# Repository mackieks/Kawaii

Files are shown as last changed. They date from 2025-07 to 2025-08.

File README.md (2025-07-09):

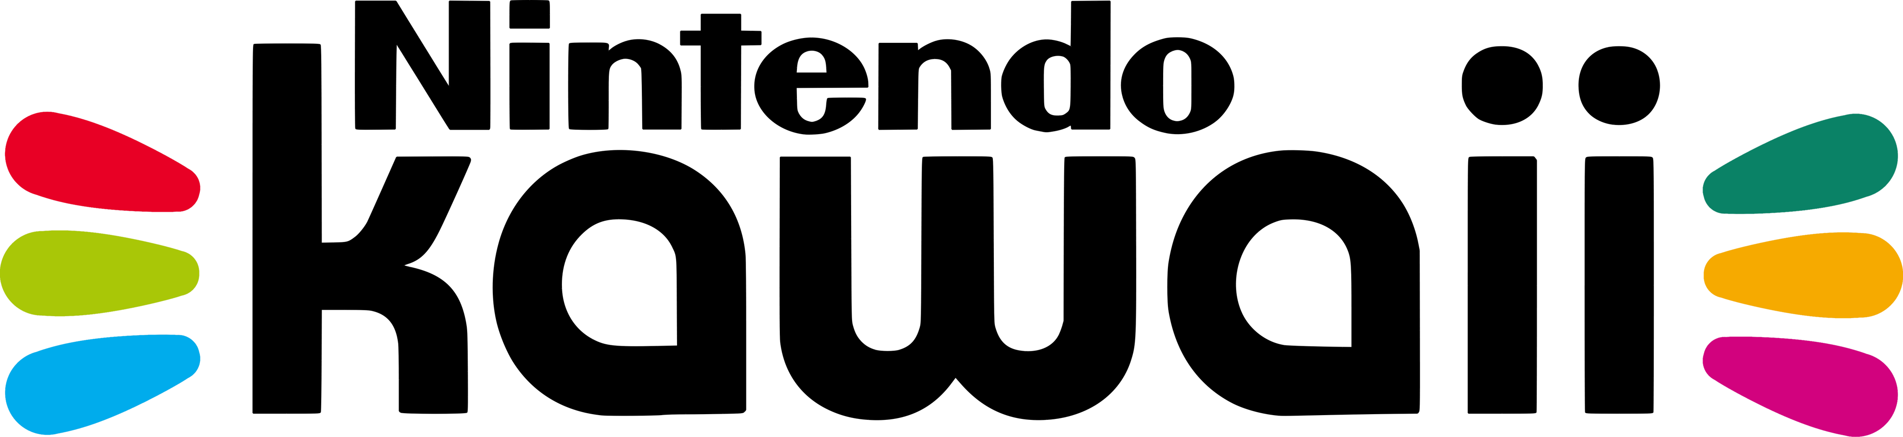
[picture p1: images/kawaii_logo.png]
<picture> <source media="(prefers-color-scheme: dark)" srcset="images/kawaii_logo_white.png">  </picture> 

Kawaii is a functional metal Nintendo Wii keychain created by YveltalGriffin, Wesk and Ding.

It's a technical tour de force that prioritizes aesthetics over practicality, and **fully** utilizes the OMEGA trim.

Kawaii may be the zenith of Wii portablizing as an artform.
  


## Features:
- [x] 60 x 60 x 15.8mm CNC aluminum chassis
- [x] Anodized, with laser-etched artwork
- [x] Fake compliance markings
- [x] Keychain / tassel loop
- [x] OMEGA-trimmed undervolted Hollywood-2 Wii Mini motherboard
- [x] [AVEflex](https://github.com/mackieks/AVEflex) and [nandFlex](https://github.com/mackieks/nandFlex)
- [x] Powered by [Thundervolt](https://github.com/mackieks/thundervolt)
- [x] Internal microSD card for homebrew and games
- [x] Six internal addressable RGB LEDs
- [x] Magnetic pogo pin docking connector
- [x] Composite video, 480p YPbPr, and stereo audio output
- [x] 4-player GameCube controller connectivity via magnetic dock

## Gallery



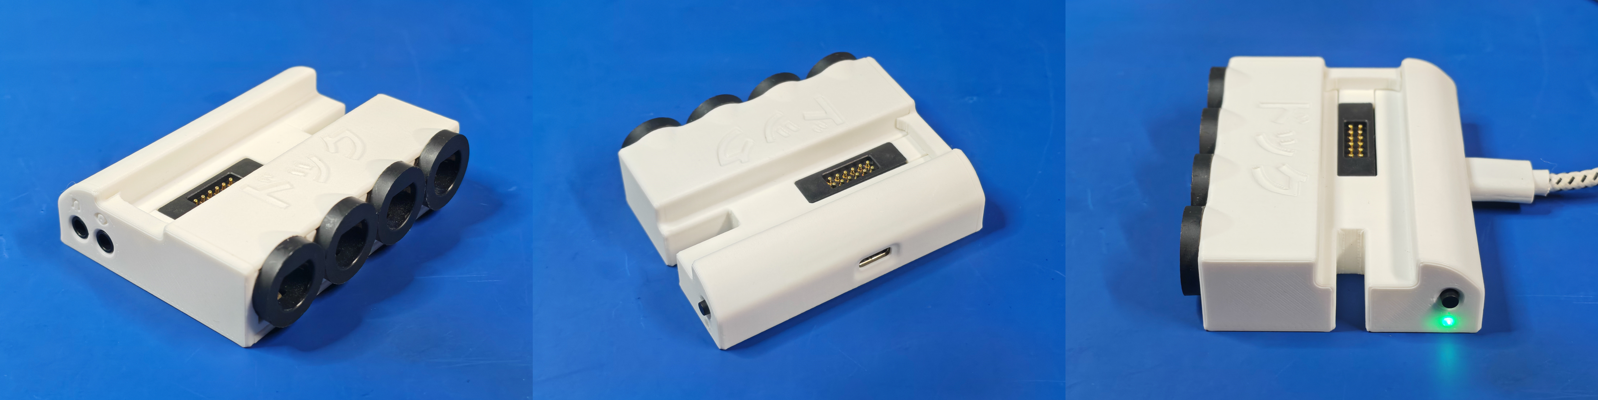
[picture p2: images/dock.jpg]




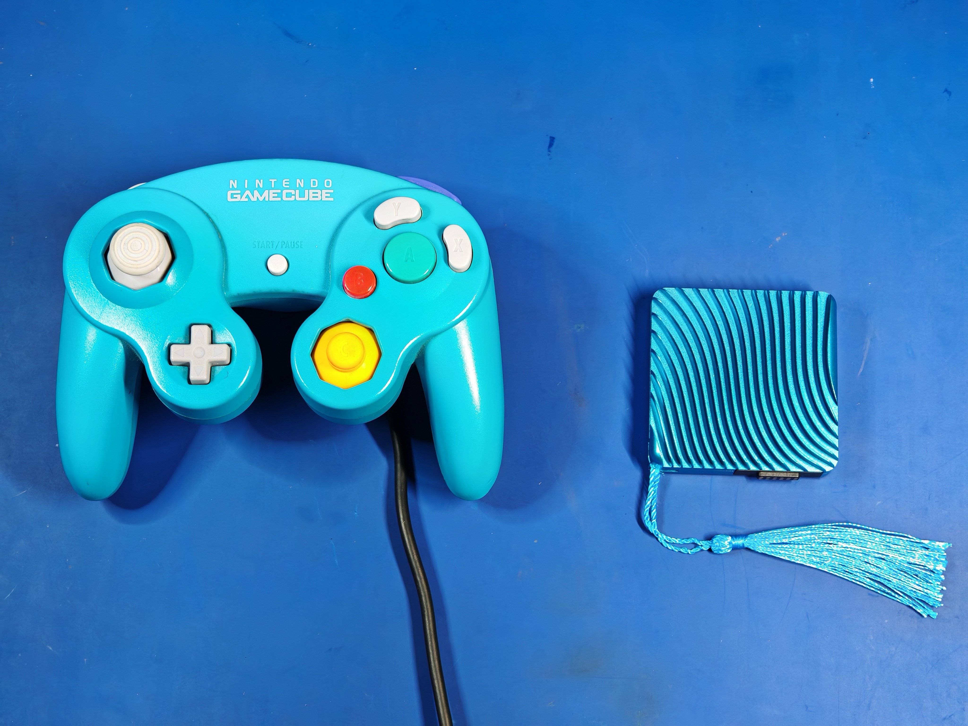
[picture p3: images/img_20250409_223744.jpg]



## Building One

Kawaii is 100% open source, but due to the extremely challenging nature of the build, no assembly guide or build tutorial is provided. Keep in mind that this project is **portablizer jewelry** (it's literally a keychain) and **NOT** a console you want to daily drive.

Check out [the hardware folder](https://github.com/mackieks/Kawaii/tree/main/hardware) for all of the MCAD, ECAD, and BOM files. A full MCAD assembly is provided in both F3D and STEP format, which shows how everything fits together. The [BitBuilt thread](https://bitbuilt.net/forums/index.php?threads/kawaii.6474/) has lots of pictures from the assembly process of two Kawaiis and is a valuable resource. 

## World's Smallest?

Whether the Kawaii is the world's smallest functioning Wii is up for debate. Since it requires a dock or bundle of adapter cables to play games on a TV, it's certainly not the world's smallest _fully self-contained_ Wii— that's still loopj's [Short Stack](https://github.com/loopj/short-stack). Kawaii also requires an external fan to stay cool enough to touch during extended use.

Still, the Kawaii does contain a complete Wii. Its only inputs are power and GameCube controllers, and its only outputs are analog audio and video. So it may be the smallest functional Wii build, but not the smallest functional Wii console. The distinction is semantic and largely irrelevant to the project's goal, which was to create something beautiful, not to claim a title. 😄

## Credits

- YveltalGriffin: Concept, ECAD, MCAD, artwork, assembly
- Wesk: MCAD, sexy renders
- Ding: CNC machining, anodization, laser etching

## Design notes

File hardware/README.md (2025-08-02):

# Hardware

The top-level MCAD assemblies in F3D and STEP format are the main reference for the overall build. STLs for the 3D-printed components are provided for convenience.

## PCB Ordering Specs:

- Dock: 1mm, ENIG recommended, electropolished stencil, [Mouser Cart](https://www.mouser.com/Tools/Project/Share?AccessID=a96e376ba1)
- kawaiiSD: 0.6mm, electropolished stencil and jig, [Mouser Cart](https://www.mouser.com/Tools/Project/Share?AccessID=177a5d7398)
- riser: 0.8mm
- rgb: 0.6mm, electropolished stencil

## List of Kawaii components:
- [x] CNC machined, anodized, and laser-etched aluminum shell (two pieces)
- [x] Hollywood-2 Wii Mini OMEGA trim, [AVEflex](https://github.com/mackieks/AVEflex), [nandFlex](https://github.com/mackieks/nandFlex), and [Thundervolt](https://github.com/mackieks/thundervolt)
- [x] Internal kawaiiSD PCB
- [x] Pogo pin riser PCB
- [x] RGB LED PCB
- [x] MHF4 female pigtails [link](https://www.aliexpress.us/item/3256802754472981.html)
- [x] 3D-printed lightpipes (x2)
- [x] 12-pin magnetic pogo pin connector [link 1](https://www.aliexpress.us/item/3256804525551011.html), [link 2](https://www.aliexpress.us/item/3256807252344568.html)
- [x] Various fasteners (see MCAD)

## List of dock components:
- [x] 3D-printed dock (three pieces)
- [x] Dock PCB (including four trimmed/cleaned-up Wii GCC ports)
- [x] LED lightpipe (PLPC2-100)
- [x] Various fasteners (see MCAD)

## Miscellaneous assembly/usage notes:
- [x] A heavily-undervolted Hollywood-2 Wii Mini is mandatory. A Hollywood-1, or any variant at stock voltages, will run way too hot
- [x] Unless you live in Alaska or Siberia, the unit will need an external source of airflow (fan, AC, open window, etc.) to stay cool enough to touch during operation
- [x] Use 0.5mm foam tape to secure the RGB LED PCB to the Kawaii shell
- [x] Use a file to post-process the Wii GCC ports. They have to be really uniform and square to fit into the shell properly (see thread)
- [x] Use a camcorder pinout 3.5mm-to-RCA cable for A/V. Check the schematic for pinout details. [link](https://www.amazon.com/dp/B08V1SV8BL)
- [x] Use a Samsung / LG pinout 3.5mm-to-component cable for YPbPR. Check the schematic for pinout details. [link](https://www.amazon.com/dp/B09ZJTZ5NL)

## License

Solderpad Hardware License v2.1

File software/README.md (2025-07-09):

## Software

Arduino RGB LED PCB firmware because nothing but Adafruit's NeoPixel library would work properly with the SK6805 LEDs. Someday I will port this to PlatformIO.

For the time being, you'll need to install SpenceKonde's megaTinyCore and the Adafruit_NeoPixel library in Arduino. Set the MCU clock speed to 16MHz.

## License

MIT

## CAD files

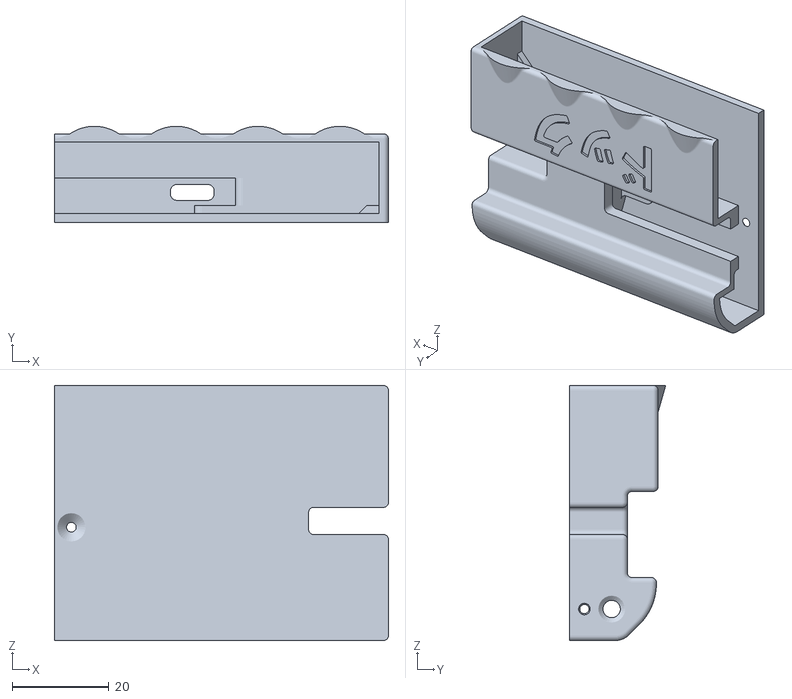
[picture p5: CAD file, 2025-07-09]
hardware/STLs/Dock Main.stl
69.0 x 19.9 x 52.7

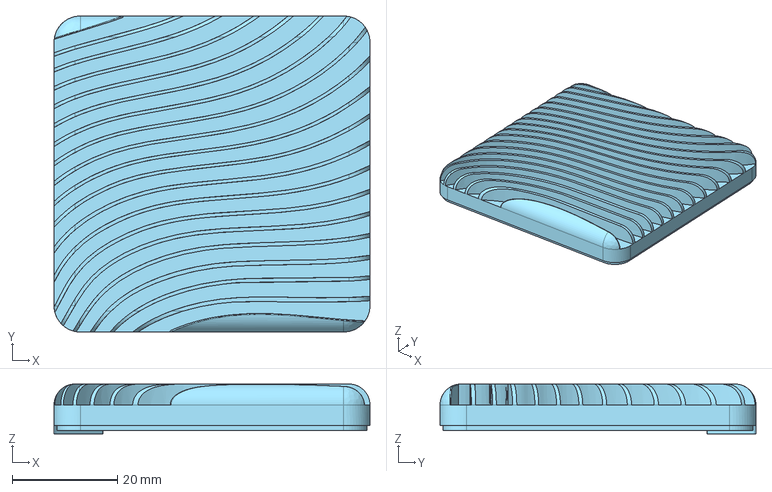
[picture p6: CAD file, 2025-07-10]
hardware/CNC/Kawaii Front.step
60.0 x 60.0 x 9.48 mm

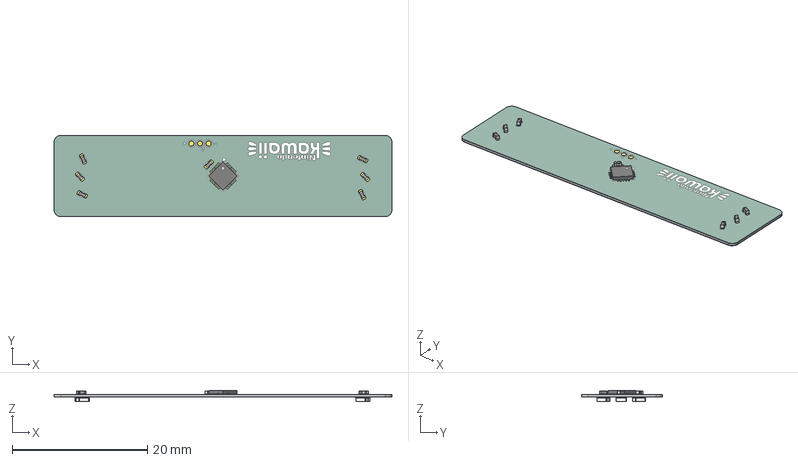
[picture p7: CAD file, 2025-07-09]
hardware/PCBs/kawaii/rgb/rgb_led.step
50.0 x 12.0 x 1.58 mm
C_0402_1005Metric x 7
UQFN-20-1EP_3x3mm_P0.4mm_EP1.85x1.85mm
kicad_embedded_893F824B369B2A560D4BFC5FC6994426 x 6
rgb_led_copper
rgb_led_silkscreen
rgb_led_soldermask
rgb_led_PCB

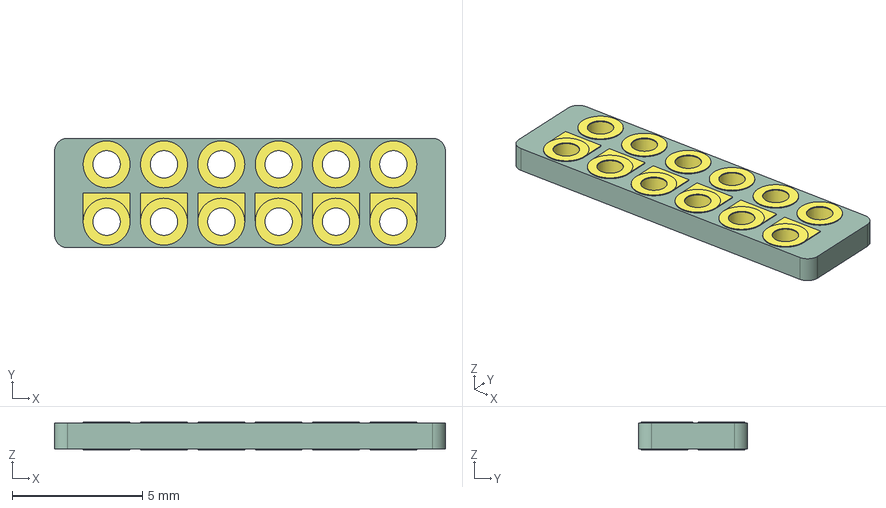
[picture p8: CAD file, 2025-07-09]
hardware/PCBs/kawaii/riser/riser.step
15.0 x 4.20 x 1.07 mm
riser_zone_1
riser_zone_2
riser_zone_3
riser_zone_4
riser_zone_5
riser_zone_6
riser_pad_1
riser_pad_2
riser_pad_3
riser_pad_4
riser_pad_5
riser_pad_6
riser_pad_7
riser_pad_8
riser_pad_9
riser_pad_10
riser_pad_11
riser_pad_12
riser_pad_13
riser_pad_14
riser_pad_15
riser_pad_16
riser_pad_17
riser_pad_18
riser_pad_19
riser_pad_20
riser_pad_21
riser_pad_22
riser_pad_23
riser_pad_24
riser_pad_25
riser_pad_26
riser_pad_27
riser_pad_28
riser_pad_29
riser_pad_30
riser_pad_31
riser_pad_32
riser_pad_33
riser_pad_34
riser_pad_35
riser_pad_36
riser_PCB

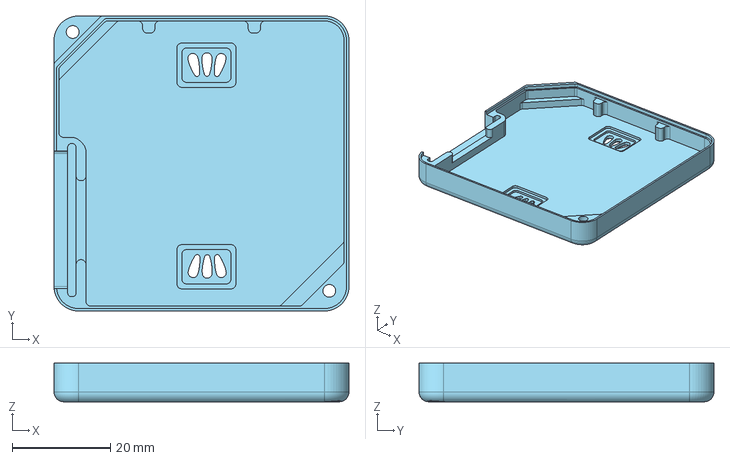
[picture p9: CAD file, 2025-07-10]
hardware/CNC/Kawaii Back.step
60.0 x 60.0 x 7.85 mm

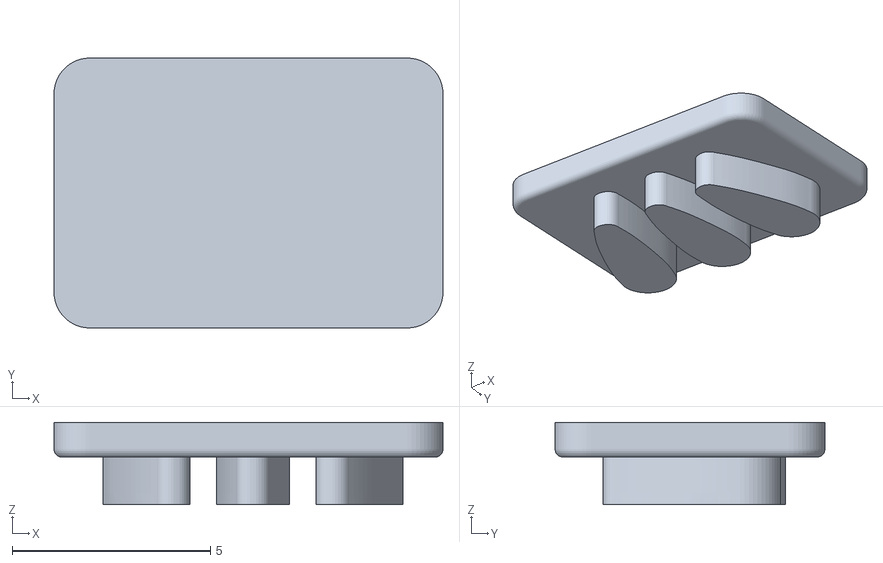
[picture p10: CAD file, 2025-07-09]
hardware/STLs/Right Lightpipe.stl
9.80 x 6.80 x 2.08

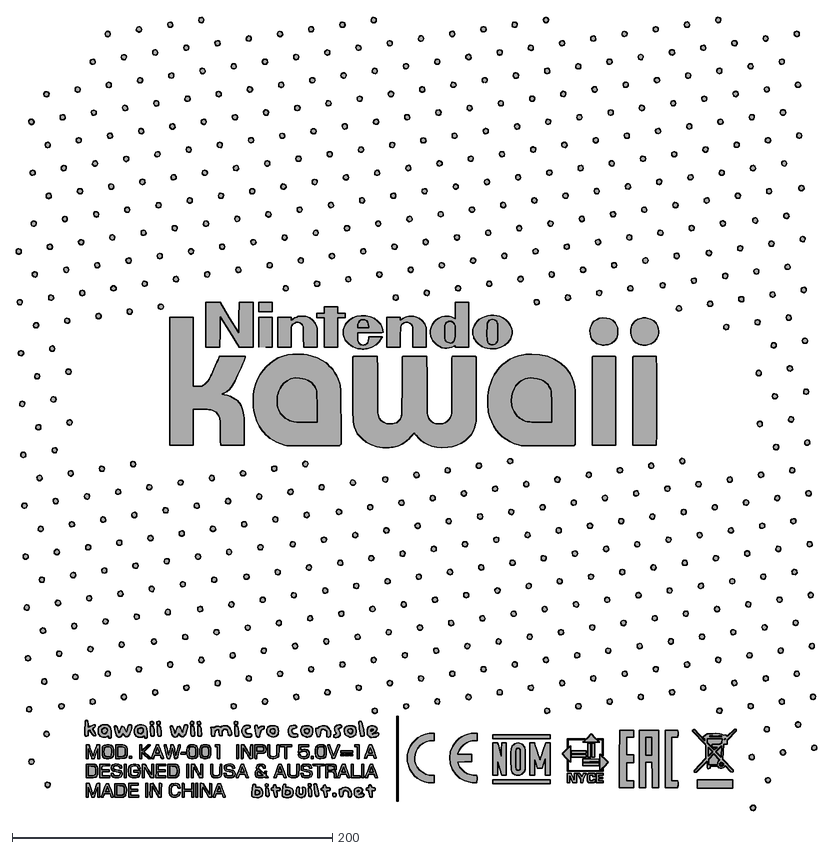
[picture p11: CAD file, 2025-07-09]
hardware/CNC/kawaii-laser-artwork.dxf
500.0 x 495.8

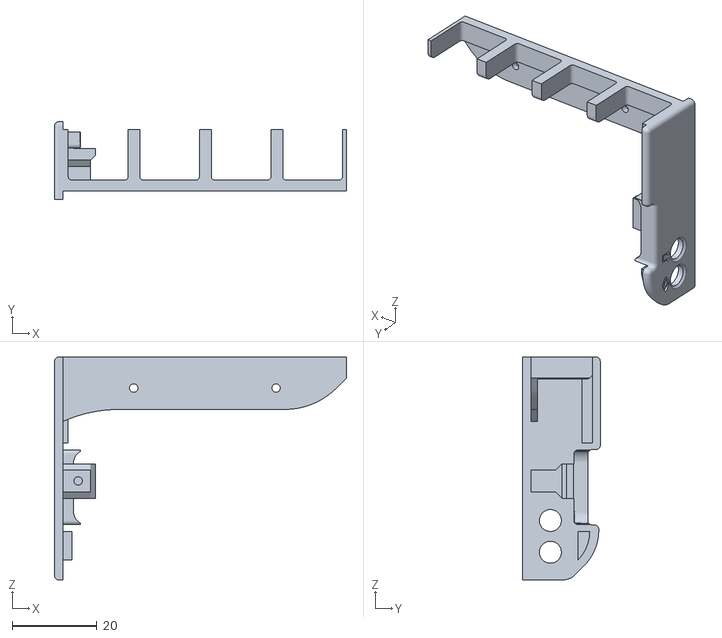
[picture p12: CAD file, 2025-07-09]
hardware/STLs/Dock Side.stl
69.0 x 18.3 x 52.7

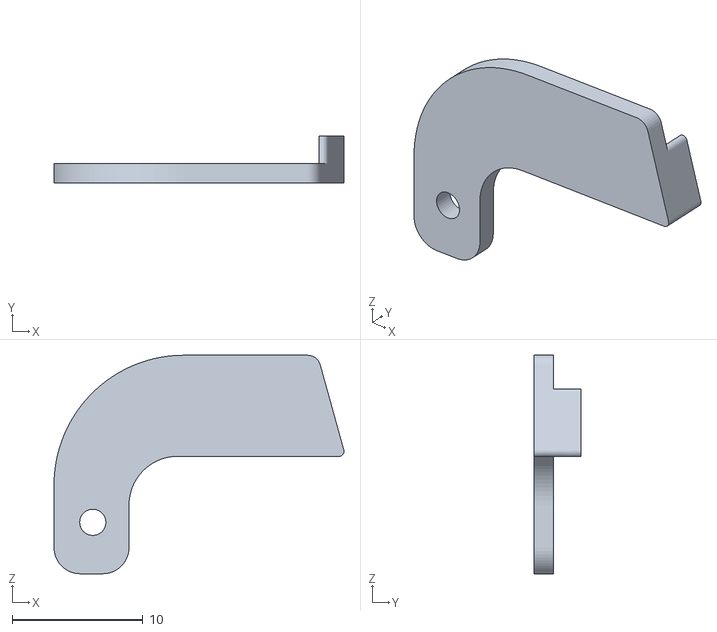
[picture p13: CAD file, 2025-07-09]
hardware/STLs/Dock Inner.stl
22.1 x 3.59 x 16.7

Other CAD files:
hardware/STLs/Left Lightpipe.stl

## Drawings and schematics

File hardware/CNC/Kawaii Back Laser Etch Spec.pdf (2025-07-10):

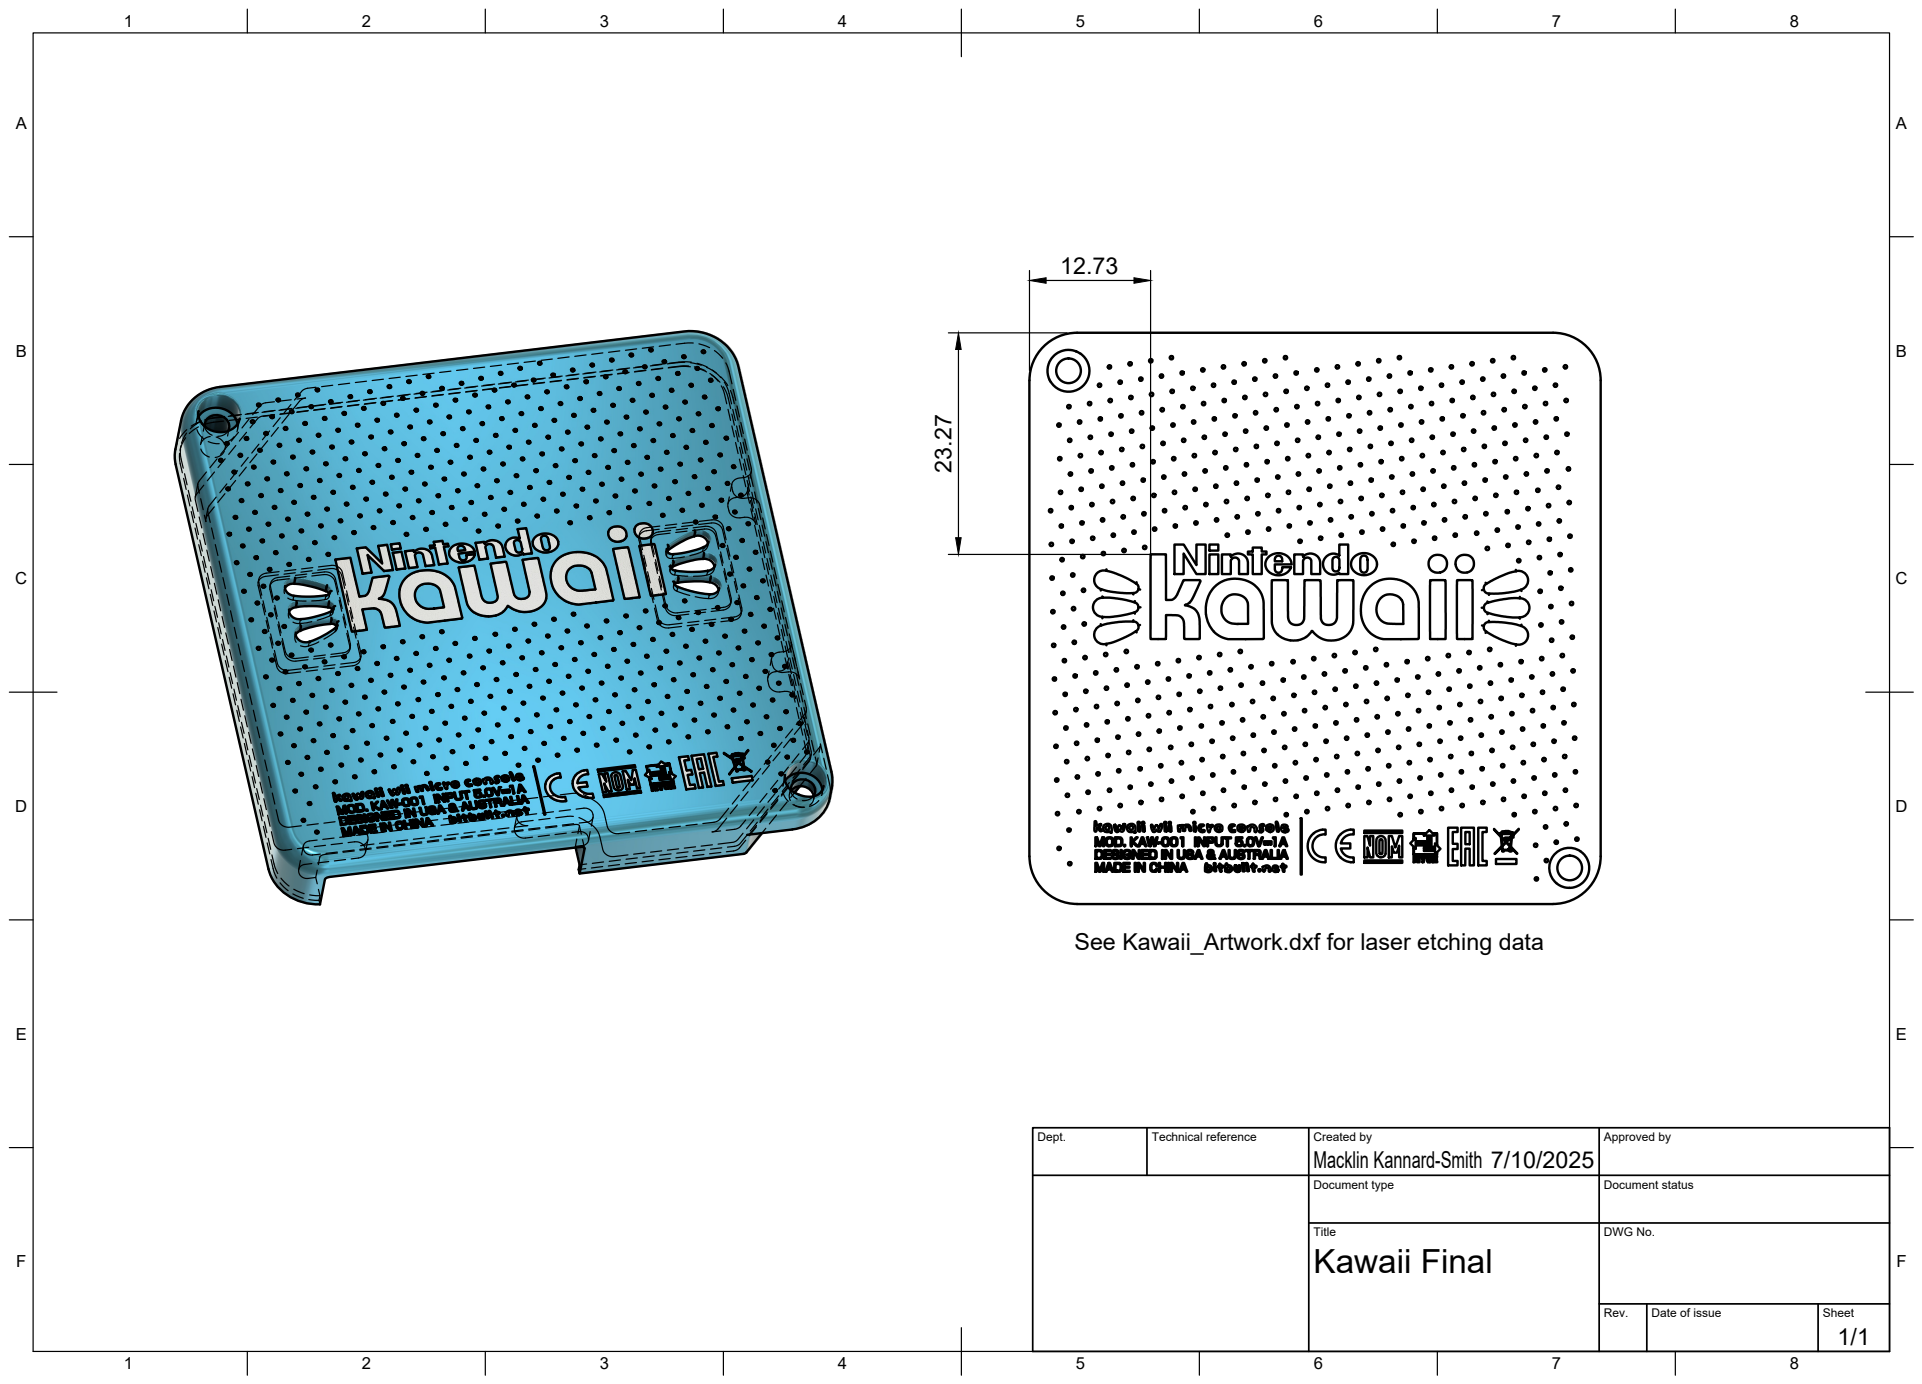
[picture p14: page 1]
Dept.; Technical reference; Created by; Approved by; Document type; Document status; Title; DWG No.; Rev.; Date of issue; Sheet; Kawaii Final

See Kawaii_Artwork.dxf for laser etching data

Macklin Kannard-Smith

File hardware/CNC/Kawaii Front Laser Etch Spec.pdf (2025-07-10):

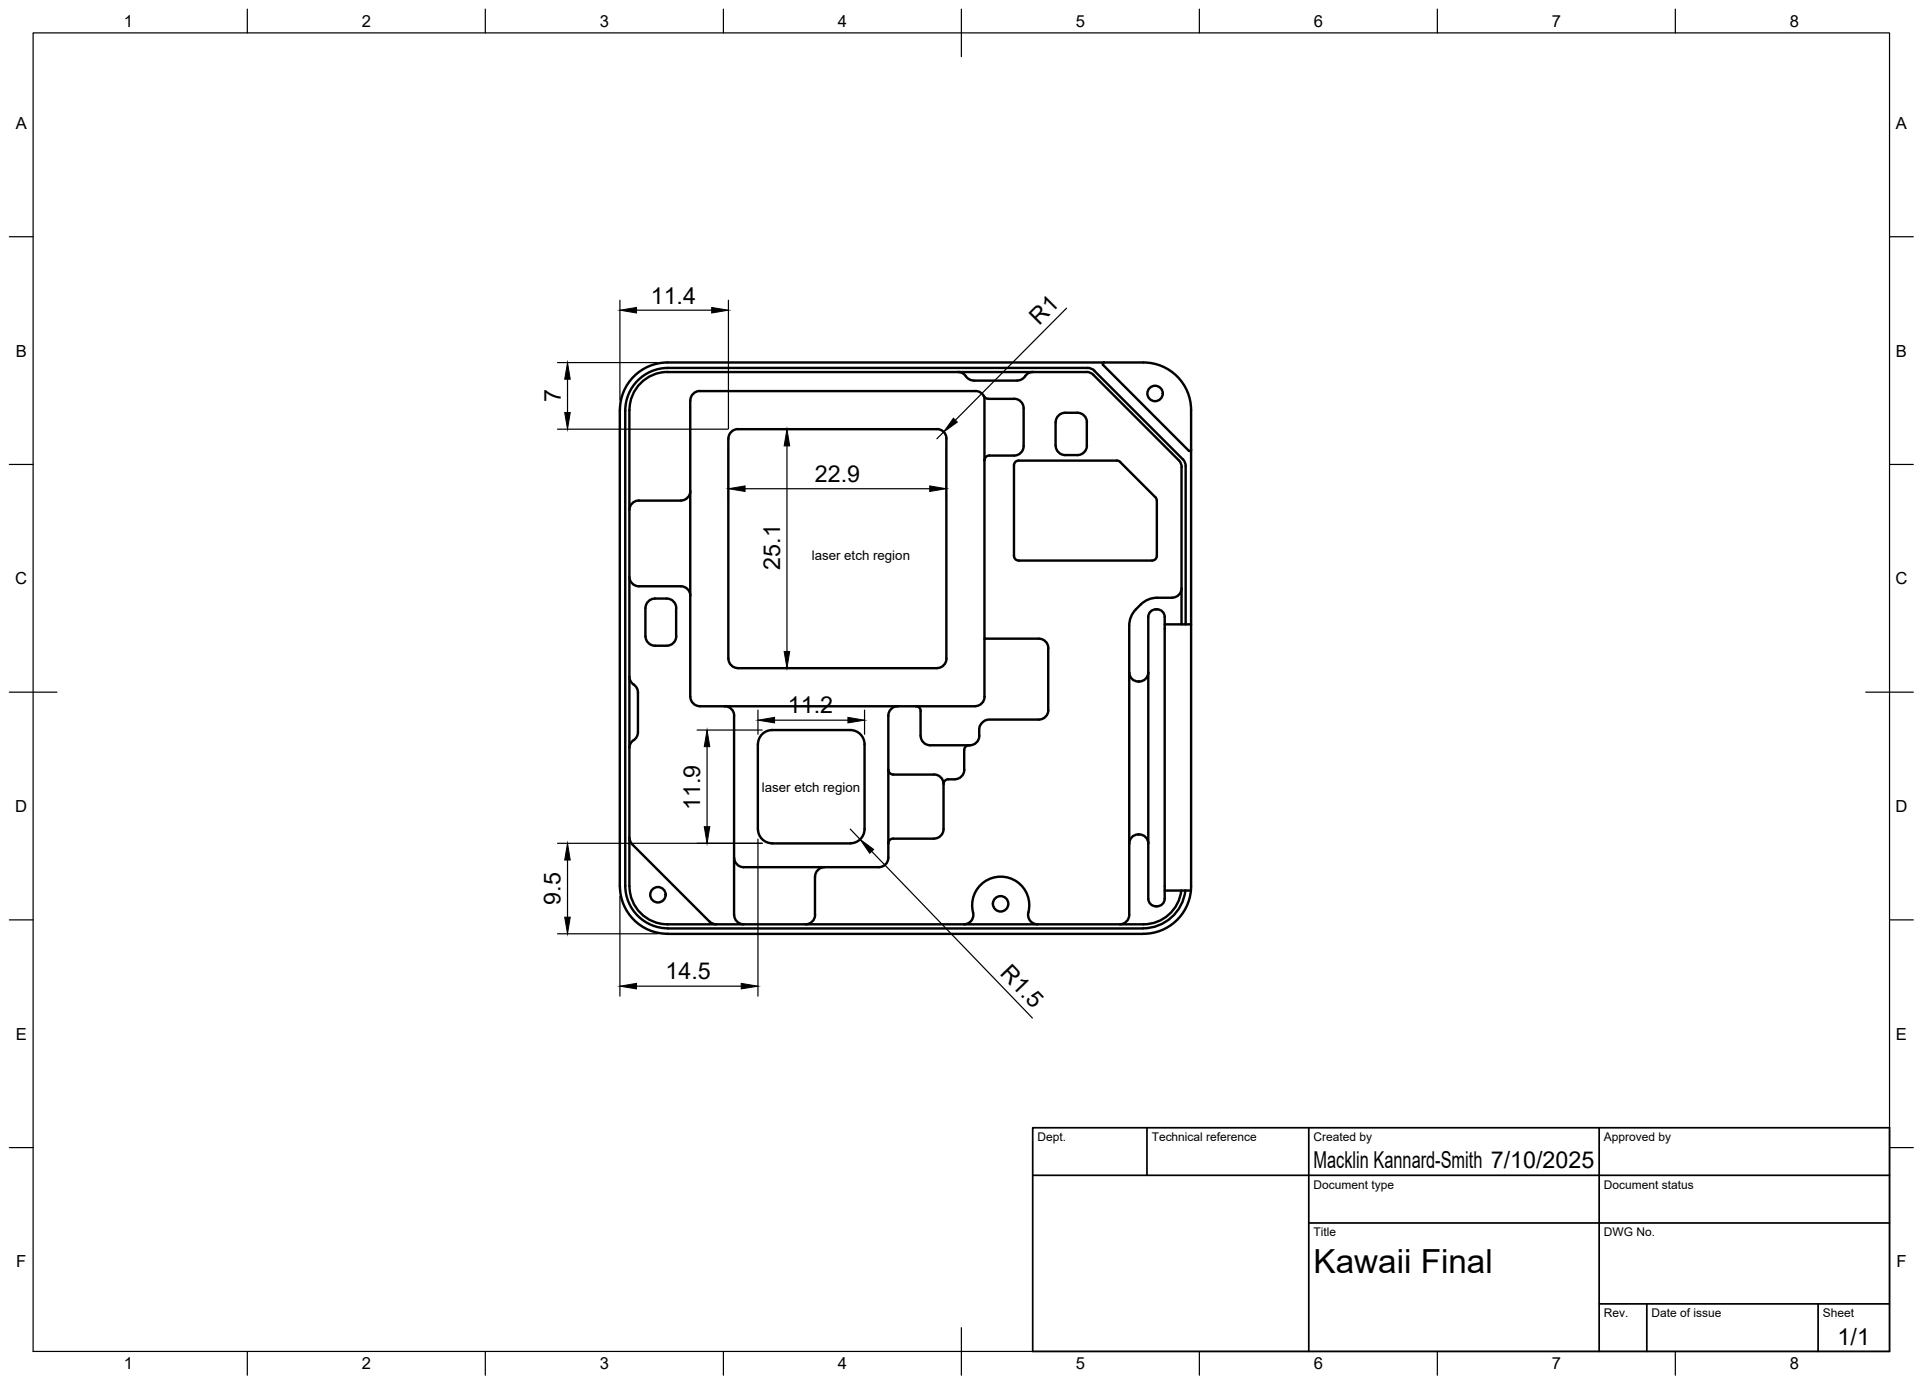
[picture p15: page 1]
Title; DWG No.; Rev.; Date of issue; Sheet; Kawaii Final

laser etch region

Dept. | Technical reference | Created by Macklin Kannard-Smith 7/10/2025 | Approved by

Document type | Document status

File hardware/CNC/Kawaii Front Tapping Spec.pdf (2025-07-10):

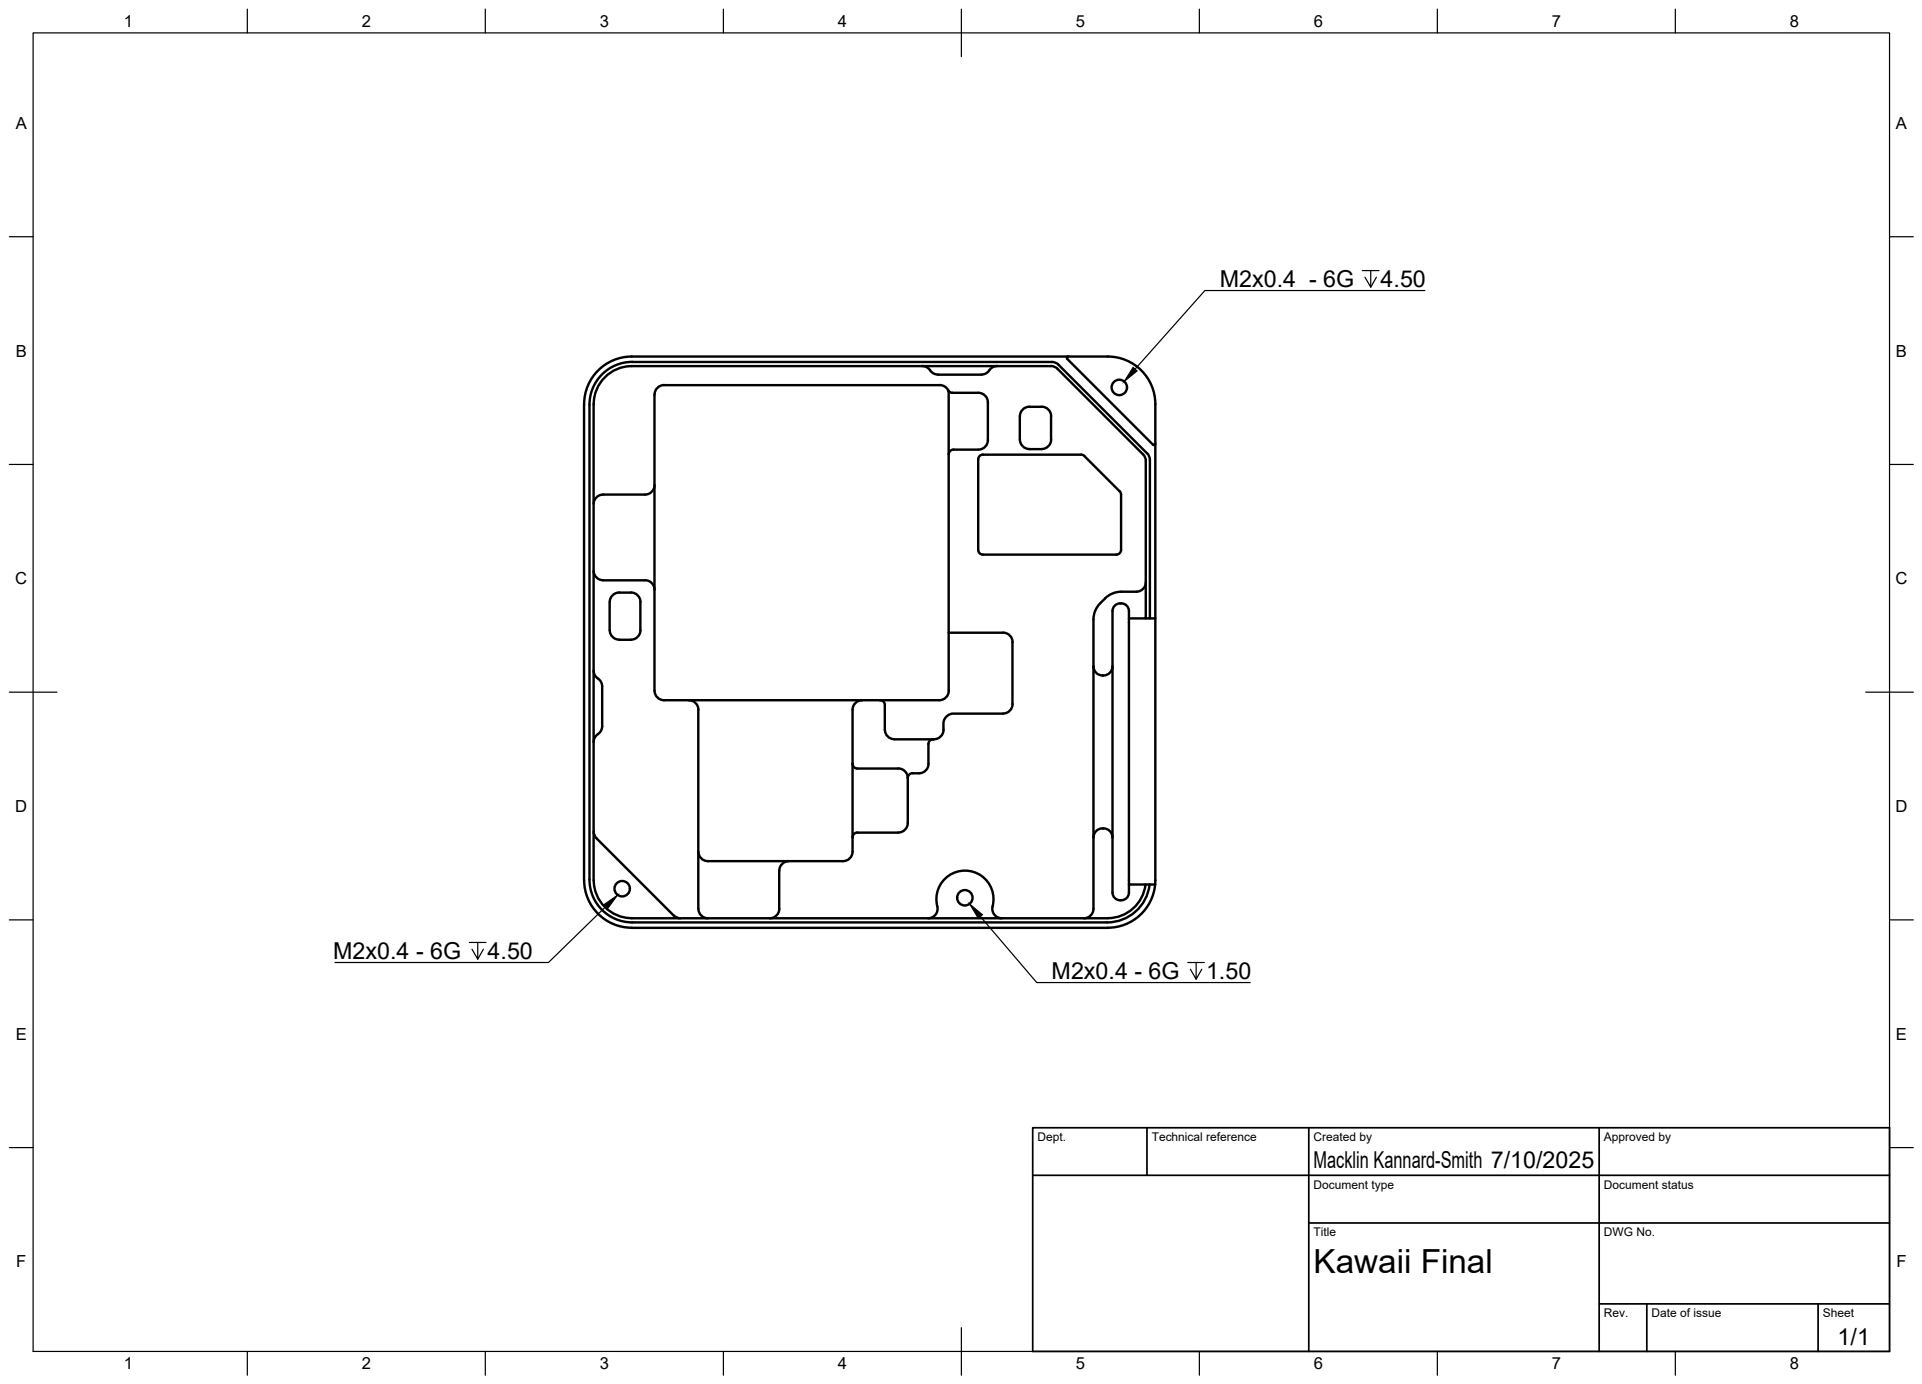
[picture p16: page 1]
Title; DWG No.; Rev.; Date of issue; Sheet; Kawaii Final

Dept. | Technical reference | Created by Macklin Kannard-Smith 7/10/2025 | Approved by

Document type | Document status

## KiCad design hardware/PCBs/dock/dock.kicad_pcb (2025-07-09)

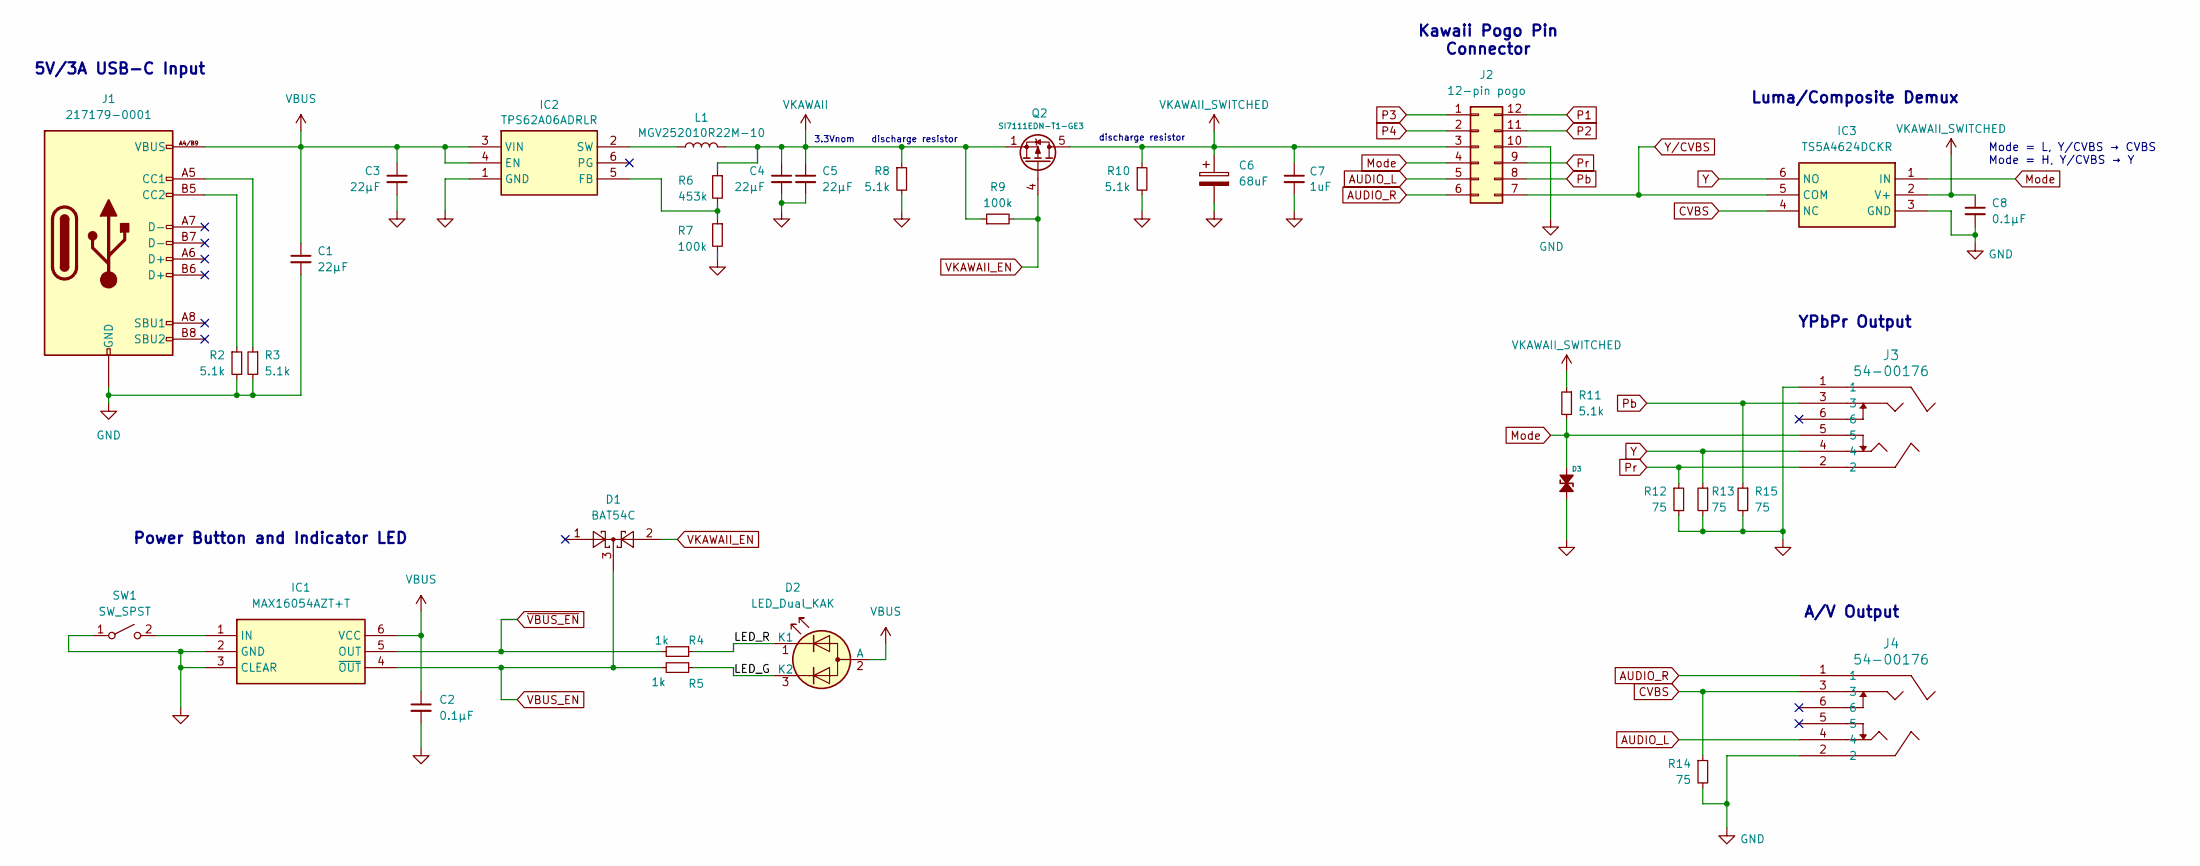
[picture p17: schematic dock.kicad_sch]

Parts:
C1, C3, C4, C5: 22μF; C_0603_1608Metric
C2, C8: 0.1μF; C_0402_1005Metric
C6: 68uF; CP_Elec_5x5.8
C7: 1uF; C_0402_1005Metric
D1: BAT54C; SOT-23
D2: LED_Dual_KAK; 155124RG73200
D3: GG0402052R542P; DIONC1006X55N
IC1: MAX16054AZT+T; SOT95P275X110-6N; Mouser Part Number 700-MAX16054AZTT
IC2: TPS62A06ADRLR; SOTFL50P160X60-6N; Mouser Part Number TPS62A06ADRLR
IC3: TS5A4624DCKR; SOT65P210X110-6N; Mouser Part Number 595-TS5A4624DCKR
J1: 217179-0001; 2171790001
J2: 12-pin pogo; pogo
J3, J4: 54-00176; 54-00176_TEN
L1: MGV252010R22M-10; L_1008_2520Metric
Q2: SI7111EDN-T1-GE3; SQS401ENT1_BE3
R2, R3, R8, R10, R11: 5.1k; R_0402_1005Metric
R4, R5: 1k; R_0402_1005Metric
R6: 453k; R_0402_1005Metric
R7, R9: 100k; R_0402_1005Metric
R12, R13, R14, R15: 75; R_0402_1005Metric
SW1: SW_SPST; 6x6x8mm_tact_ra

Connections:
/LED_G: D2.3 (K2), R5.1
/LED_R: D2.1 (K1), R4.1
AUDIO_L: J2.5, J4.4
AUDIO_R: J2.6, J4.1
CVBS: IC3.4 (NC), J4.3, R14.1
GND: C1.2, C2.2, C3.2, C4.2, C5.2, C6.2, C7.2, C8.2, D3.1 (A1), IC1.2 (GND), IC1.3 (CLEAR), IC2.1 (GND), IC3.3 (GND), J1.1 (GND), J1.2 (GND), J1.3 (GND), J1.4 (GND), J1.13 (GND), J1.14 (GND), J1.15 (GND), J1.16 (GND), J1.A1/B12 (GND_2), J1.B1/A12 (GND), J1.S_1_H1 (GND), J1.S_1_H2 (GND), J1.S_2_H1 (GND), J1.S_2_H2 (GND), J1.S_3_H1 (GND), J1.S_3_H2 (GND), J1.S_4_H1 (GND), J1.S_4_H2 (GND), J2.10, J3.1, J4.2, R2.2, R3.2, R7.2, R8.2, R10.2, R12.2, R13.2, R14.2, R15.2, SW1.1 (A); also elsewhere on the board
Mode: D3.2 (A2), IC3.1 (IN), J2.4, J3.5, R11.2
unnamed: IC1.1 (IN), SW1.2 (B)
unnamed: IC2.5 (FB), R6.2, R7.1
unnamed: IC2.2 (SW), L1.1
unnamed: J1.A5 (CC1), R3.1
unnamed: J1.B5 (CC2), R2.1
P1: J2.12; also elsewhere on the board
P2: J2.11; also elsewhere on the board
P3: J2.1; also elsewhere on the board
P4: J2.2; also elsewhere on the board
Pb: J2.8, J3.3, R15.1
Pr: J2.9, J3.2, R12.1
VBUS: C1.1, C2.1, C3.1, D2.2 (A), IC1.6 (VCC), IC2.3 (VIN), IC2.4 (EN), J1.A4/B9 (VBUS), J1.B4/A9 (VBUS); also elsewhere on the board
VBUS_EN: D1.3, IC1.4 (~OUT), R5.2
VKAWAII: C4.1, C5.1, L1.2, Q2.1 (S), Q2.2 (S), Q2.3 (S), R6.1, R8.1, R9.1
VKAWAII_EN: D1.2, Q2.4 (G), R9.2
VKAWAII_SWITCHED: C6.1, C7.1, C8.1, IC3.2 (V+), J2.3, Q2.5 (D), Q2.6 (D), Q2.7 (D), Q2.8 (D), Q2.9 (D), R10.1, R11.1; also elsewhere on the board
Y: IC3.6 (NO), J3.4, R13.1
Y/CVBS: IC3.5 (COM), J2.7
~VBUS_EN: IC1.5 (OUT), R4.2

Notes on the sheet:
Mode = L, Y/CVBS → CVBS Mode = H, Y/CVBS → Y
Luma/Composite Demux
Kawaii Pogo Pin Connector
Power Button and Indicator LED
discharge resistor
YPbPr Output
A/V Output
3.3Vnom
5V/3A USB-C Input

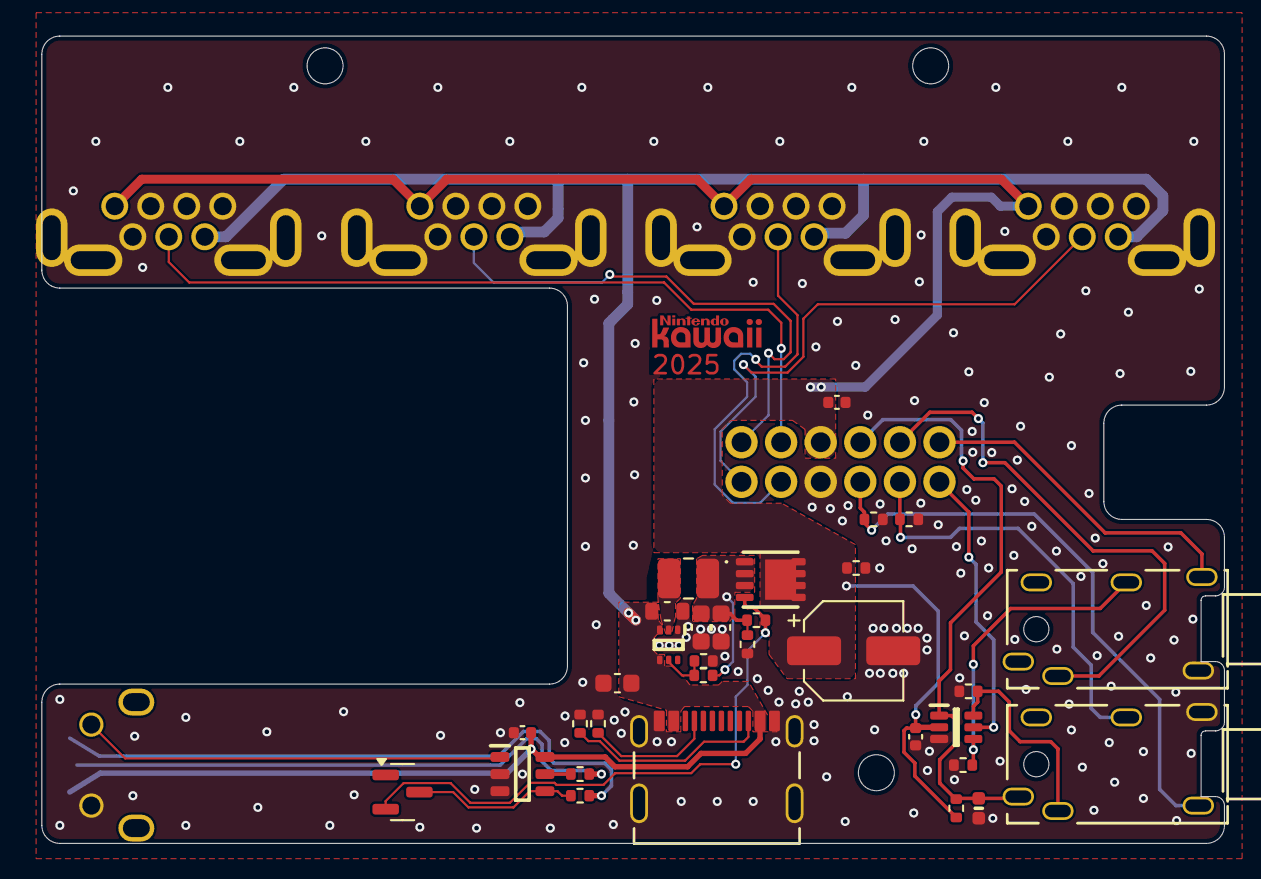
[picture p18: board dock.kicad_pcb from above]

Board: 2 copper layers, 65.7 x 44.8 mm, 39 parts (1 on the bottom side), 26 nets.

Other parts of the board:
J5, J6, J7, J8: Wii GCC Port; gcc

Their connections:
GND: J5.2, J5.3, J5.4, J5.5, J5.8, J5.9, J6.2, J6.3, J6.4, J6.5, J6.8, J6.9, J7.2, J7.3, J7.4, J7.5, J7.8, J7.9, J8.2, J8.3, J8.4, J8.5, J8.8, J8.9; also elsewhere on the board
P1: J8.6; also elsewhere on the board
P2: J7.6; also elsewhere on the board
P3: J6.6; also elsewhere on the board
P4: J5.6; also elsewhere on the board
VBUS: J5.7, J6.7, J7.7, J8.7; also elsewhere on the board
VKAWAII_SWITCHED: J5.1, J6.1, J7.1, J8.1; also elsewhere on the board

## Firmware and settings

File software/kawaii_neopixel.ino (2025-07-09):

#include <Adafruit_NeoPixel.h>

#define PIN        PIN_PC2
#define NUMPIXELS  6
#define DELAYVAL   20  // Optimal for smoothness
#define VALUE      100 // Brightness

Adafruit_NeoPixel pixels(NUMPIXELS, PIN, NEO_GRB + NEO_KHZ800);

const uint16_t hueOffsets[6] = {0, 256, 512, 768, 1024, 1280}; 

uint32_t hsvToRgbSmooth(uint16_t h) {
    h %= 1536; // Wrap at 6*256
    uint8_t hueSegment = h >> 8; // 0-5
    uint8_t pos = h & 0xFF;     // Position in segment

    uint8_t r, g, b;
    switch(hueSegment) {
        case 0: r=255; g=pos; b=0; break;       // Red to Yellow
        case 1: r=255-pos; g=255; b=0; break;   // Yellow to Green
        case 2: r=0; g=255; b=pos; break;       // Green to Cyan
        case 3: r=0; g=255-pos; b=255; break;  // Cyan to Blue
        case 4: r=pos; g=0; b=255; break;      // Blue to Magenta
        default: r=255; g=0; b=255-pos; break; // Magenta to Red
    }
    
    // Apply brightness
    return pixels.Color(
        (r * VALUE) >> 8,
        (g * VALUE) >> 8,
        (b * VALUE) >> 8
    );
}

void setup() {
  pixels.begin();
  pixels.clear();
}

void loop() {
  static uint16_t hue = 0; // 16-bit for smoothness

  for(uint8_t i=0; i<NUMPIXELS; i++) {
    pixels.setPixelColor(i, hsvToRgbSmooth(hue + hueOffsets[i]));
  }

  pixels.show();
  hue += 6;
  delay(DELAYVAL);
}

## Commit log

2025-07-09 Add everything!
    [Dock Inner.stl, Dock Main.stl, Dock Side.stl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]
2025-07-10 Reorganize CAD, add technical drawings
    [Kawaii Back.step, Kawaii Front.step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]
